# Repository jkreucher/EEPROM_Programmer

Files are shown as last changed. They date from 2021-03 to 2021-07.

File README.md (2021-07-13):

# Simple EEPROM Programmer

Copyright 2021 Jannik Kreucher

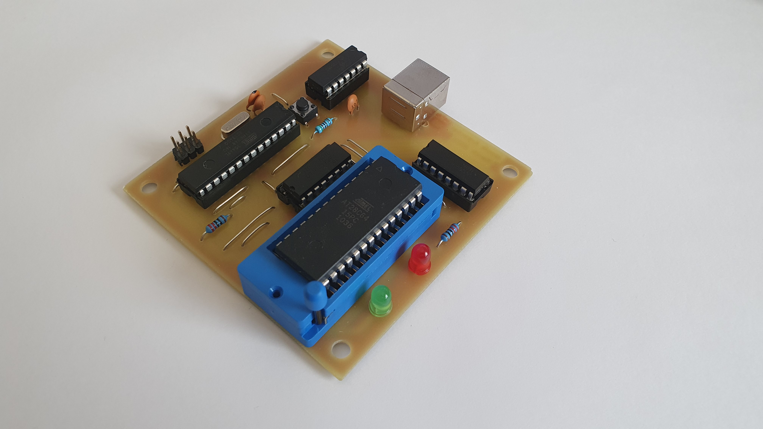
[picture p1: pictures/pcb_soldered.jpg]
PCB


## Table of Contents
 - [Project](#project)
 - [Dependencies](#dependencies)
 - [Make](#make)
 - [Flash EEPROM](#flash-eeprom)
 - [Schematic](#schematic)
   - [Processor](#micro-processor)
   - [Shift Registers](#shift-registers)
   - [EEPROM](#eeprom)
 - [PCB](#pcb)
 - [Enclosure](#enclosure)
 - [License](#license)

## Project

I created this programmer for my personal Z80 project. Since commerical programmers are fairly expensive I created my own simple programmer. It is nothing fancy and just supports a single family of [EEPROMs](https://en.wikipedia.org/wiki/EEPROM). It does not have support for a higher programming voltage and is limited for +5V EEPROMs.

This simple programmer supports following EEPROMs:
 - [28c64 (8k)](http://ww1.microchip.com/downloads/en/devicedoc/doc0001h.pdf)
 - [28c256 (32k)](http://ww1.microchip.com/downloads/en/DeviceDoc/doc0006.pdf)

## Dependencies

To compile the code you need to have following tools installed:
 - avr-gcc (with avr-libs)
 - avrdude
 - uisp

The programmer flash tool uses [Python3](https://www.python.org/) and [pySerial](https://pyserial.readthedocs.io/en/latest/pyserial.html):
 - python3
 - python3-serial

The Makefile contains a command to install everything needed:
```
cd code
sudo make tools
```

## Make

First compile the ATmega code. Execute following in the project root folder:
```
cd code
make
```

Now flash the compiled code to the programmer. *Connect the ISP-Programmer* and execute:
```
make fuses
make upload
```
I am using a USBasp Programmer. **Note: Notch on ISP-Programmer must be facing the ATmega8 chip (U1) while flashing firmware.**

## Flash EEPROM

**Note: Firmware needs to be flashed beforehand !**

To flash your binary file to the EEPROM inserted type:
```
cd code
chmod +x eeprom.py
./eeprom.py -e -o -p /dev/ttyACM0 -b 115200 -w <binaryfile.bin>
```

For more information:
```
./eeprom.py -h
```

## Schematic

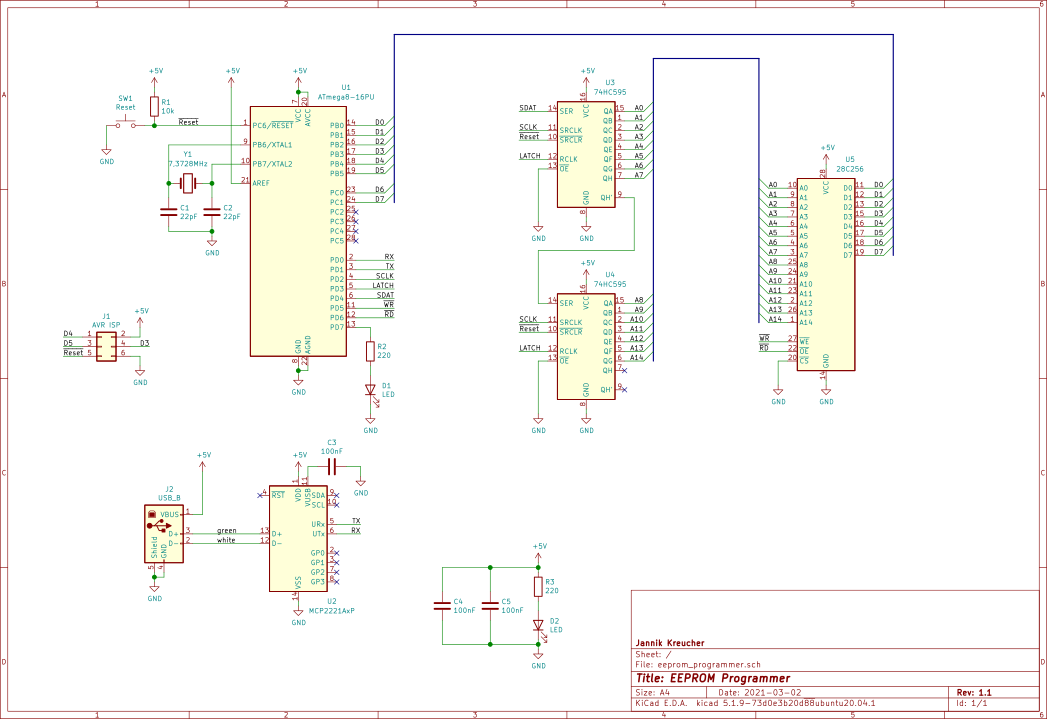
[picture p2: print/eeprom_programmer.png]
Schematic


### Micro Processor
The micro processor used in this project is the popular [ATmega8 (U1)](https://ww1.microchip.com/downloads/en/DeviceDoc/Atmel-2486-8-bit-AVR-microcontroller-ATmega8_L_datasheet.pdf), a cheaper version of the ATmega328 used in the [Arduino Uno](https://store.arduino.cc/arduino-uno-rev3). It handles everything: the serial communication, address bus and the data bus. U2 (MCP2221) handles the USB to UART conversion so no external ftdi cable is needed. The supply voltage is conveniantly given by the USB port also. Because data bus of the EEPROM is bidirectional it is directly connected to the processor. The micro processor needs to handle setting the bus as input or output. See [`eeprom.c`](code/eeprom.c) for everything I/O related. The UART is handled in [`uart.c`](code/uart.c). And the communication protocol is defined in [`parser.c`](code/parser.c) and in [`main.c`](code/main.c).

### Shift Registers
The shift registers (U3, U4) are utilized to expand the IO of the processor. Just 3 bits are needed to set the address bus to the target address. Since the address bus is only one way no data needs to be read from the address bus thus making shift registers the obvious choice for this situation. See [`eeprom.c: addrbus_set()`](code/eeprom.c) for how the data is latched.

### EEPROM

The EEPROM uses a parallel interface for communication. The address bus (A0-A14) is a parallel input which sets the memory location to read or write. The control lines ~WE and ~OE (active low) tell the EEPROM to read or write from/to the memory. The data is read from or sent out the parallel data bus (D0-D7) depending on the state of the control lines. Some EEPROMs have Write-Protect enabled. A algorithm (see datasheet) is implemented to deactivate write protection. See [`eeprom.c: eeprom_disable_protect()`](code/eeprom.c) for how this works.

## PCB

Note: The pcb is designed so that the top layer represents jumpers. The vias are large enough to stick a wire through.

For the schematic and pcb layout I used [KiCad](https://kicad.org/), a very awsome open source EDA. The clearances and spaces are designed for diy home etching so nothing really fancy. See [`eeprom_programmer_bom.pdf`](bom/eeprom_programmer_bom.pdf) for the bill of materials. At the moment the whole project would cost you around 26€ plus a weekend of time.

PCB

## Enclosure

The very simple, easy and fast to print enclosure consists of two parts which sandwhich the pcb. Needed are just *4x M3,5x12mm* wood screws to assemble the enclosure.

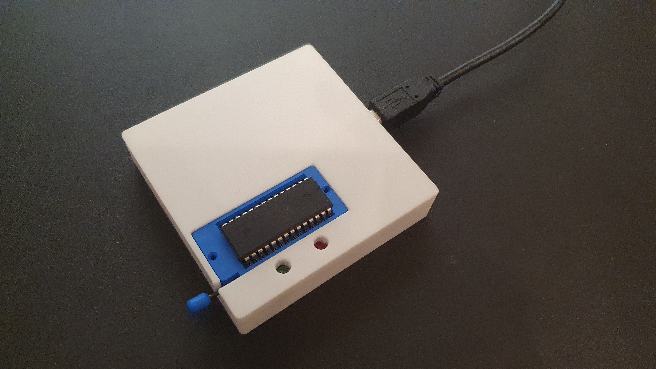
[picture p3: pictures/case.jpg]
Enclosure


## License

[MIT](LICENSE) Jannik Kreucher

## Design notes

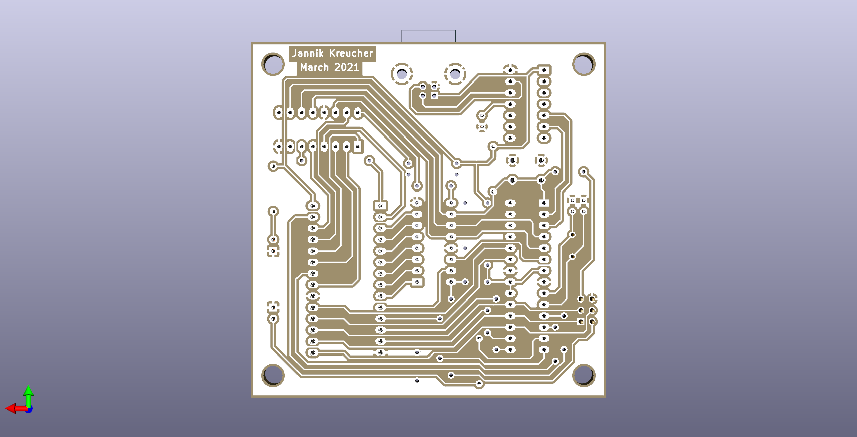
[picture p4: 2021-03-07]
pictures/eeprom_programmer_pcb_back.png

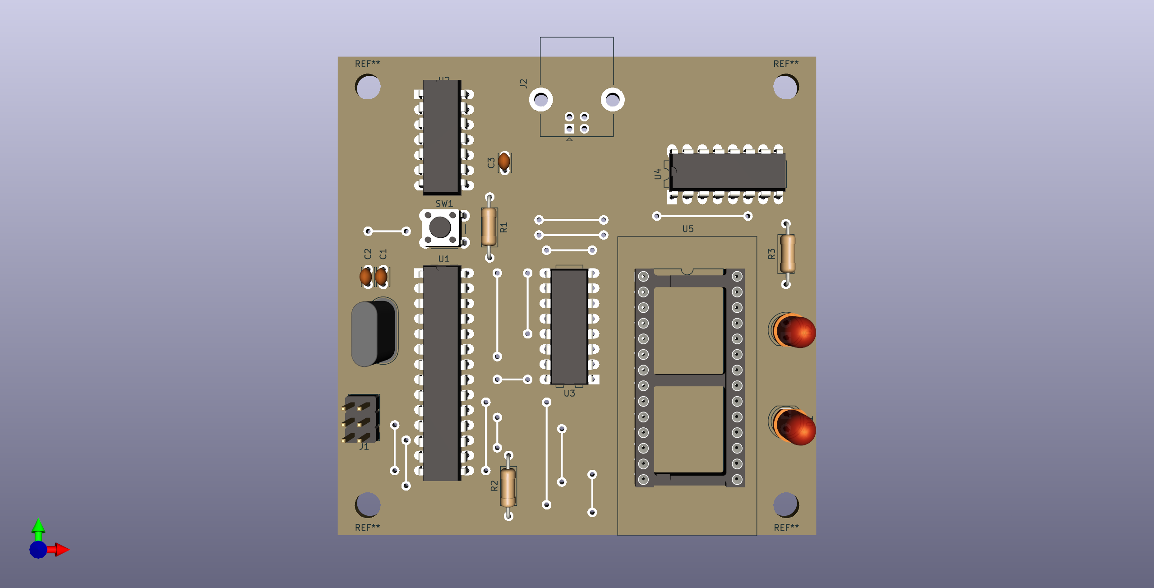
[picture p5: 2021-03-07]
pictures/eeprom_programmer_pcb_front.png

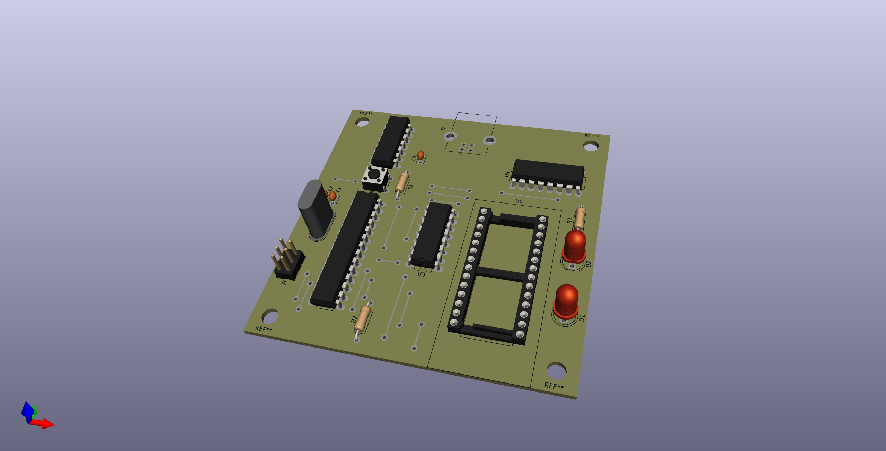
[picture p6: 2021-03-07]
pictures/eeprom_programmer_pcb_3d.png

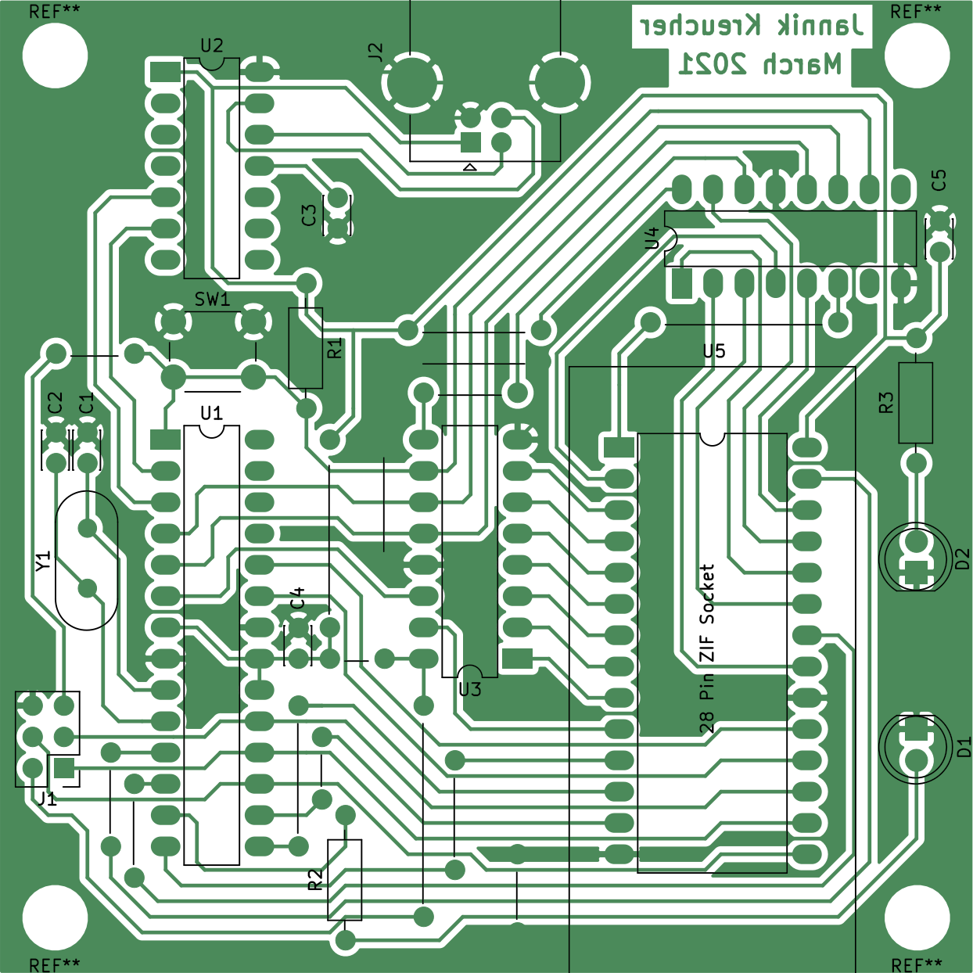
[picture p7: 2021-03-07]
gerber/eeprom_programmer-overlay.png

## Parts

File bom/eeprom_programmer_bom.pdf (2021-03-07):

# EEPROM Programmer BOM

07.03.2021 | Page 1
Designator | Value | Count | Shop | Order Num | Price | Sum
C1, C2 | 22pF | 2 | Reichelt.de | KERKO 22P | 0,051 € | 0,10 €
C3, C4, C5 | 100nF | 3 | Reichelt.de | KERKO 100N | 0,072 € | 0,22 €
D1, D2 | LED 5mm | 2 | Reichelt.de | LED 5MM GN | 0,070 € | 0,14 €
J1 | 02x03 Header | 1 | Reichelt.de | MPE 087-2-006 | 0,140 € | 0,14 €
J2 | USB Type B | 1 | Reichelt.de | USB BW | 0,300 € | 0,30 €
R1 | 10k | 1 | Reichelt.de | METALL 10,0K | 0,082 € | 0,08 €
R2, R3 | 220 | 2 | Reichelt.de | METALL 220 | 0,082 € | 0,16 €
SW1 | 6mm Switch | 1 | Reichelt.de | TASTER 9302 | 0,160 € | 0,16 €
U1 | ATmega8 | 1 | Reichelt.de ATMEGA 8-16 DIP | 1,620 € | 1,62 €
U2 | MCP2221 | 1 | Reichelt.de | MCP 2221-I/P | 2,350 € | 2,35 €
U3, U4 | 74HC595 | 2 | Reichelt.de | 74HC 595 | 0,310 € | 0,62 €
U5 | 28Pin ZIF | 1 | Reichelt.de | TEX 28 | 11,300 € | 11,30 €
Y1 | 7,3728MHz | 1 | Reichelt.de | 7,3728-HC49U-S | 0,220 € | 0,22 €
PCB | FR4 120x80 | 1 | Reichelt.de | EPCU 120X80 | 1,500 € | 1,50 €
Jumper | 0,6mm Wire | 1 | Reichelt.de | ZINN 0,6-40M | 6,550 € | 6,55 €
| | | | | Sum: | 25,46 €

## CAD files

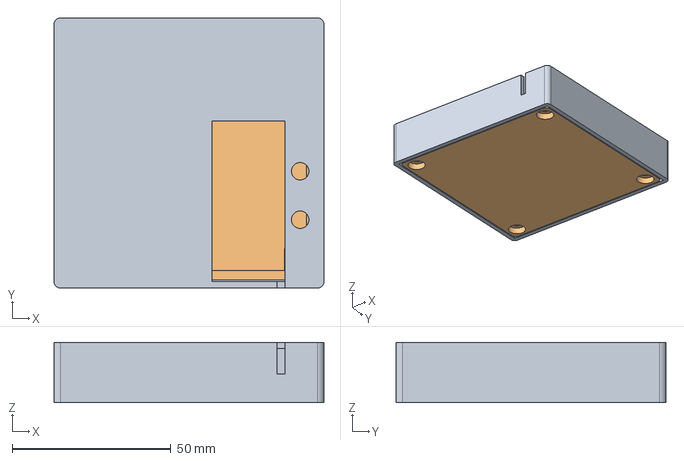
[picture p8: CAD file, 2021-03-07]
enclosure/eeprom_programmer_enclosure.FCStd
85.0 x 85.0 x 19.0 mm
Top_Part
Bottom_Part

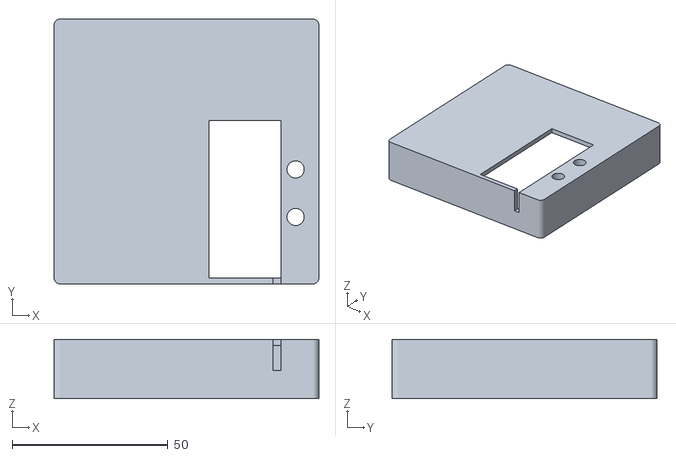
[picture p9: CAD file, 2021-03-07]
enclosure/eeprom_programmer_enclosure-Top_Part.stl
85.0 x 85.0 x 19.0

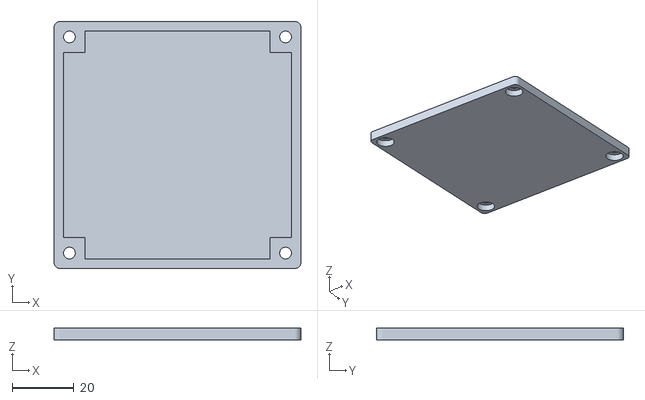
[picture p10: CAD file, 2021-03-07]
enclosure/eeprom_programmer_enclosure-Bottom_Part.stl
80.0 x 80.0 x 4.00

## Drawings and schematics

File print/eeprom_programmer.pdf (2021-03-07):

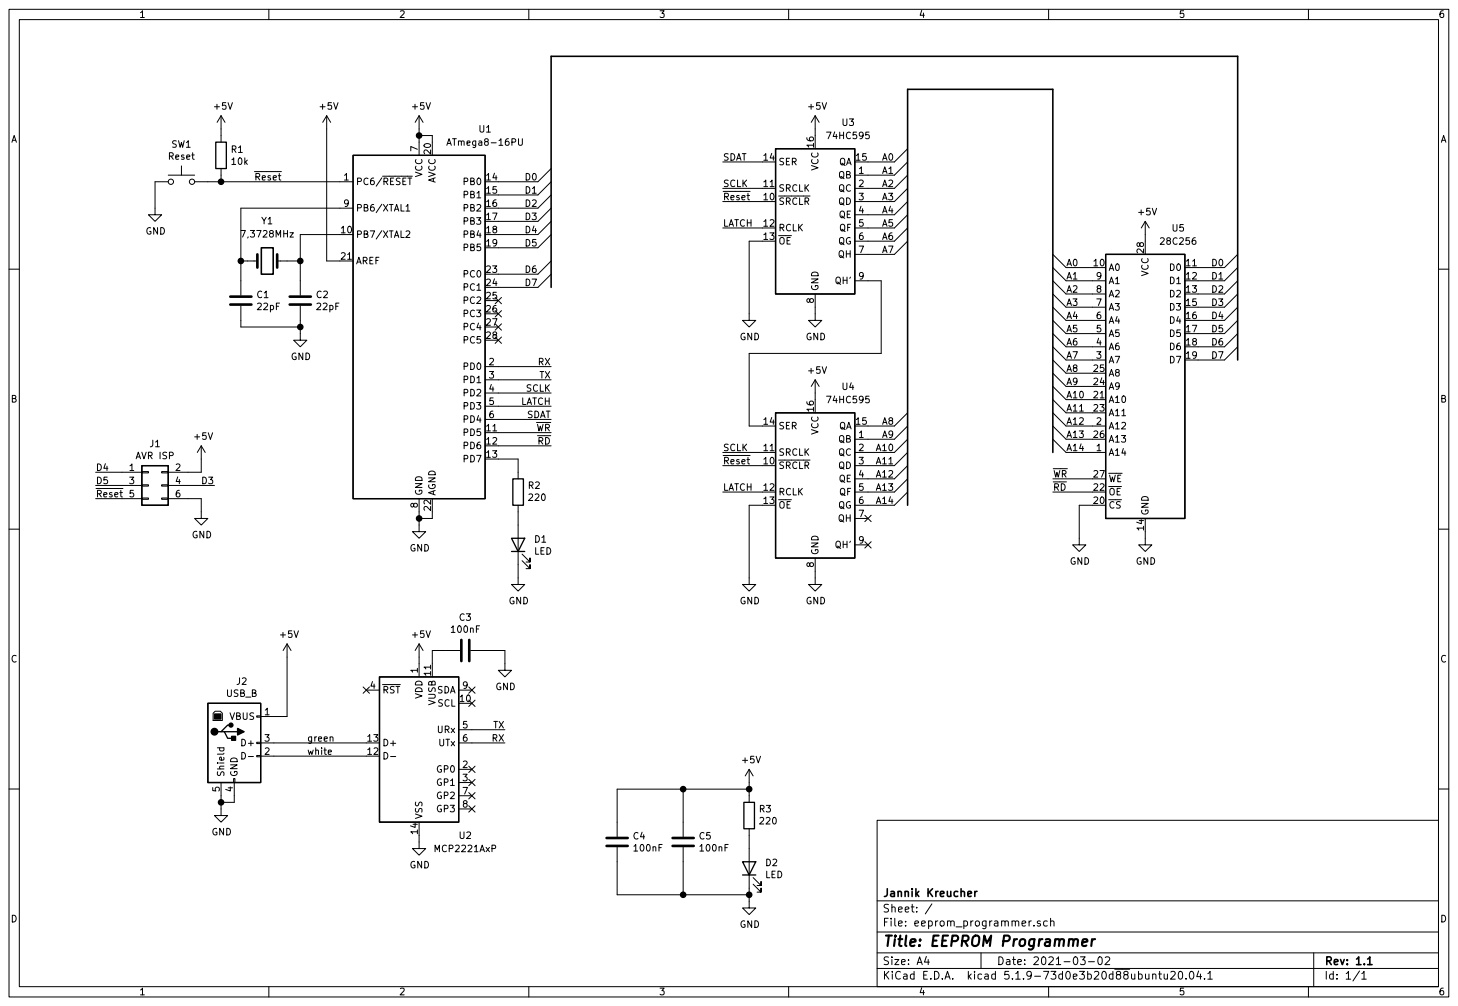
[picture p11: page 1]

74HC595 +5V GND GND GND GND

Id: 1/1 Title: EEPROM Programmer

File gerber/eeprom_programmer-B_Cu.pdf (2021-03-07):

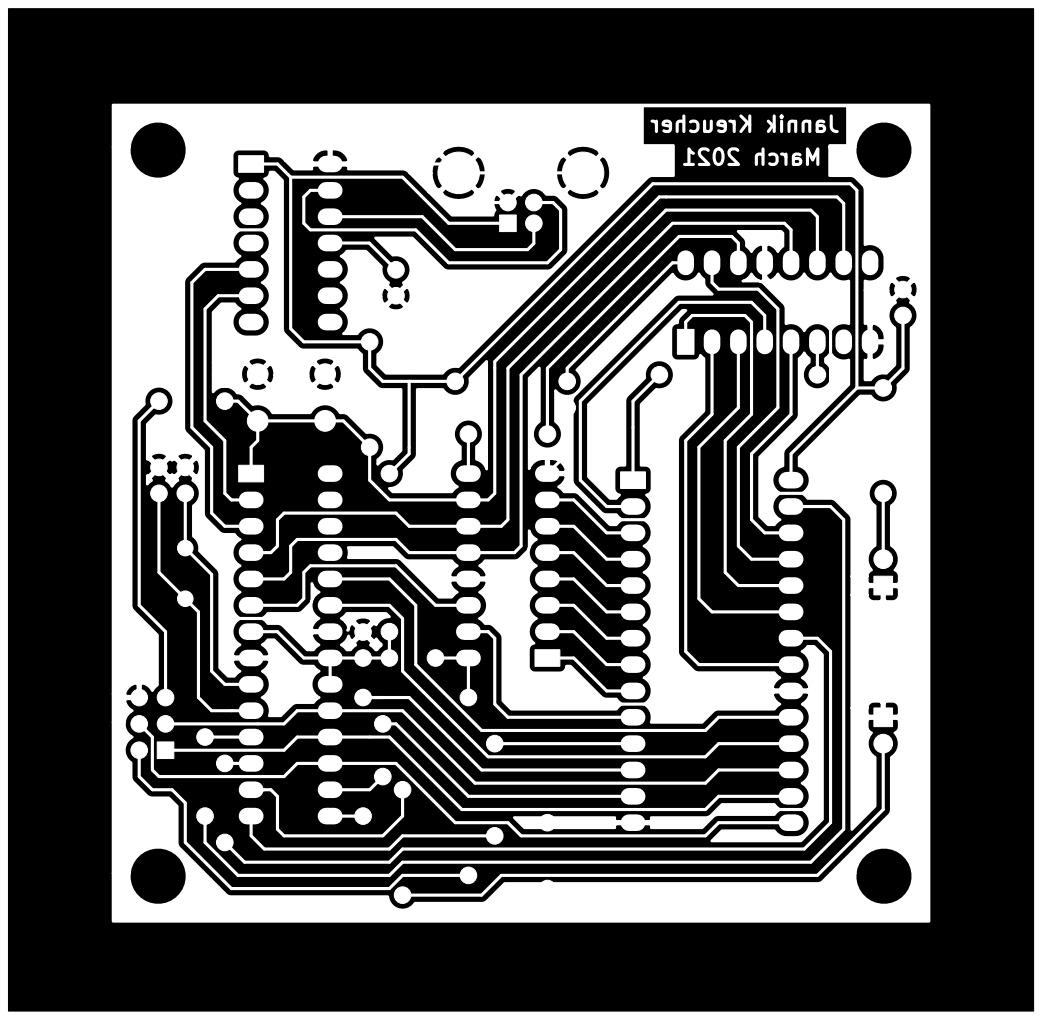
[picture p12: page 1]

File: eeprom_programmer.kicad_pcb Sheet: Jannik Kreucher Note: front Layer are wire jumpers

Id: 1/1 Title: EEPROM Programmer

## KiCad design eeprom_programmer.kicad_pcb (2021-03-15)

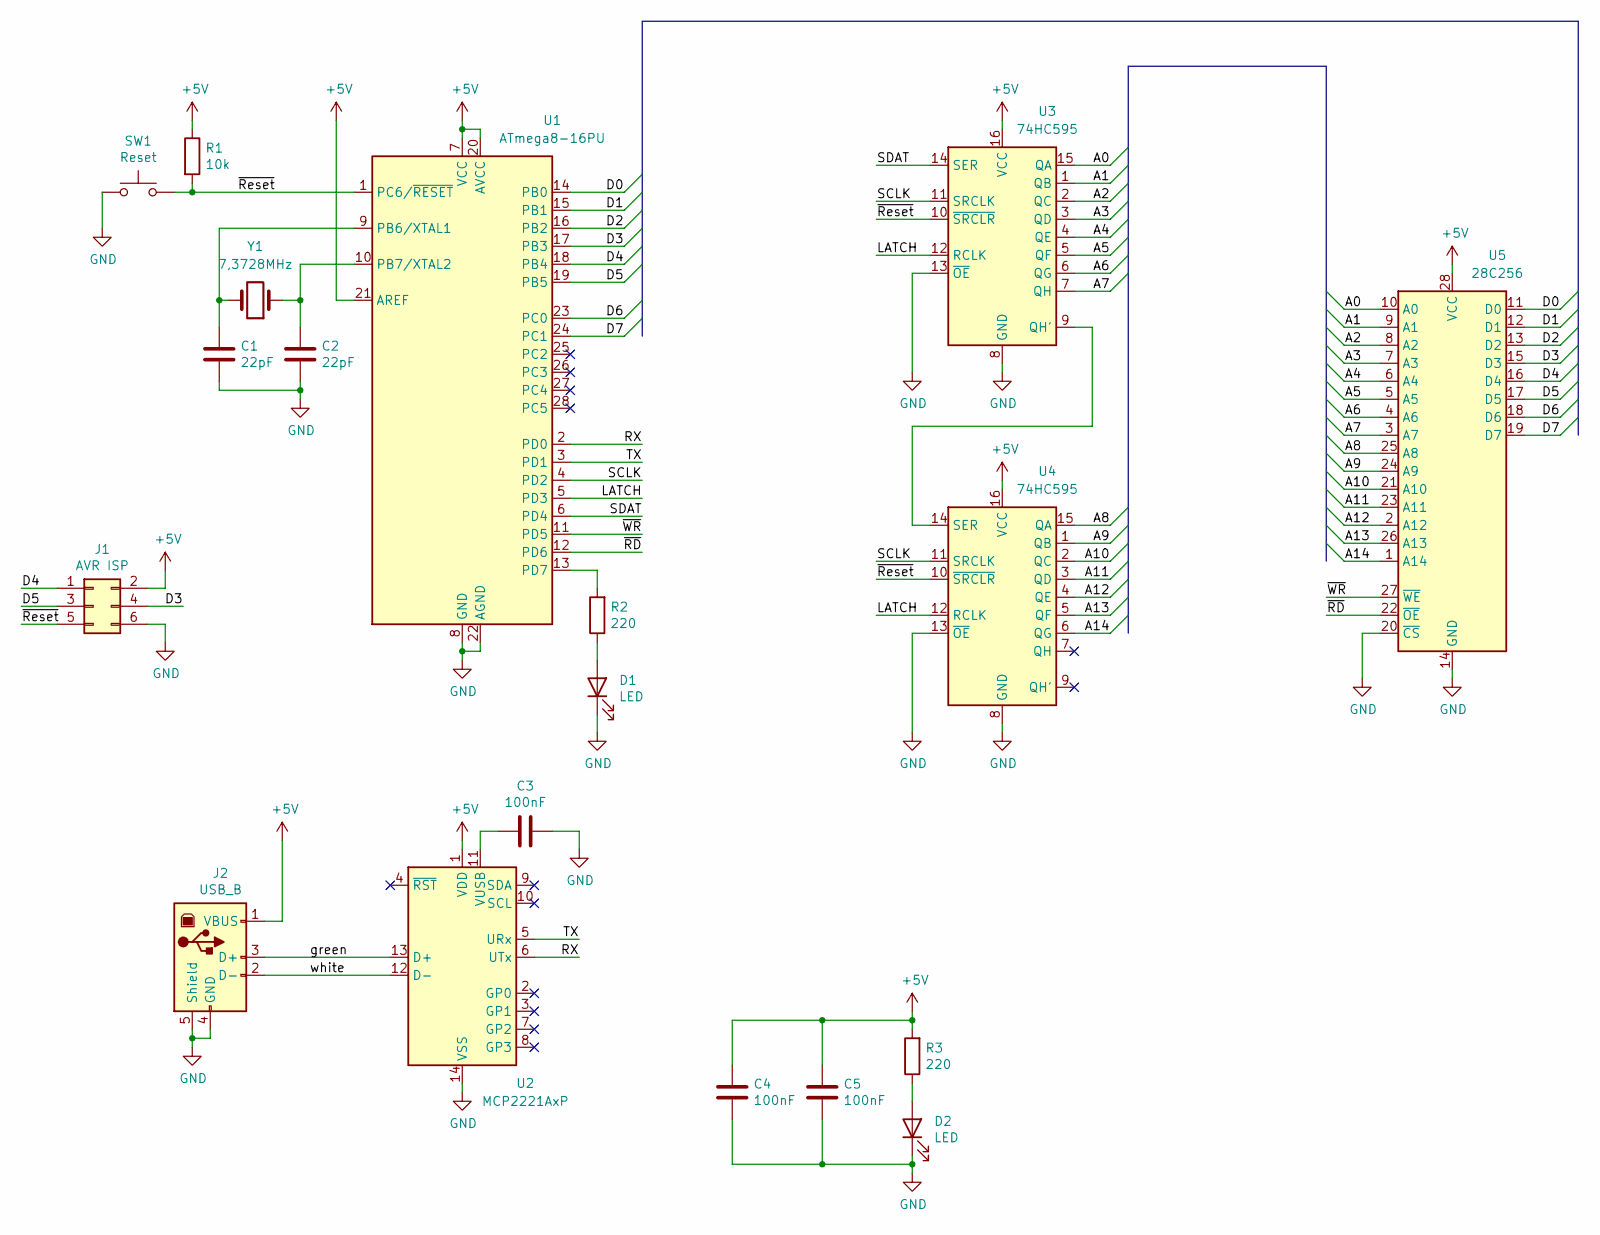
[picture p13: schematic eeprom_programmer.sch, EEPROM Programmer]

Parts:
C1, C2: 22pF; C_Disc_D3.0mm_W2.0mm_P2.50mm
C3, C4, C5: 100nF; C_Disc_D3.0mm_W2.0mm_P2.50mm
D1, D2: LED; LED_D5.0mm
J1: AVR ISP; PinHeader_2x03_P2.54mm_Vertical
J2: USB_B; USB_B_Lumberg_2411_02_Horizontal
R1: 10k; R_Axial_DIN0207_L6.3mm_D2.5mm_P10.16mm_Horizontal
R2, R3: 220; R_Axial_DIN0207_L6.3mm_D2.5mm_P10.16mm_Horizontal
SW1: Reset; SW_PUSH_6mm
U1: ATmega8-16PU; DIP-28_W7.62mm_LongPads
U2: MCP2221AxP; DIP-14_W7.62mm_LongPads
U3, U4: 74HC595; DIP-16_W7.62mm_LongPads
U5: 28C256; DIP-28_W15.24mm_ZIF_LongPads
Y1: 7,3728MHz; Crystal_HC49-U_Vertical

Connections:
+5V: C4.1, C5.1, J1.2, J2.1 (VBUS), R1.1, R3.2, U1.7 (VCC), U1.20 (AVCC), U1.21 (AREF), U2.1 (VDD), U3.16 (VCC), U4.16 (VCC), U5.28 (VCC)
/A0: U3.15 (QA), U5.10 (A0)
/A1: U3.1 (QB), U5.9 (A1)
/A2: U3.2 (QC), U5.8 (A2)
/A3: U3.3 (QD), U5.7 (A3)
/A4: U3.4 (QE), U5.6 (A4)
/A5: U3.5 (QF), U5.5 (A5)
/A6: U3.6 (QG), U5.4 (A6)
/A7: U3.7 (QH), U5.3 (A7)
/A8: U4.15 (QA), U5.25 (A8)
/A9: U4.1 (QB), U5.24 (A9)
/A10: U4.2 (QC), U5.21 (A10)
/A11: U4.3 (QD), U5.23 (A11)
/A12: U4.4 (QE), U5.2 (A12)
/A13: U4.5 (QF), U5.26 (A13)
/A14: U4.6 (QG), U5.1 (A14)
/D0: U1.14 (PB0), U5.11 (D0)
/D1: U1.15 (PB1), U5.12 (D1)
/D2: U1.16 (PB2), U5.13 (D2)
/D3: J1.4, U1.17 (PB3), U5.15 (D3)
/D4: J1.1, U1.18 (PB4), U5.16 (D4)
/D5: J1.3, U1.19 (PB5), U5.17 (D5)
/D6: U1.23 (PC0), U5.18 (D6)
/D7: U1.24 (PC1), U5.19 (D7)
/LATCH: U1.5 (PD3), U3.12 (RCLK), U4.12 (RCLK)
/RX: U1.2 (PD0), U2.6 (UTx)
/SCLK: U1.4 (PD2), U3.11 (SRCLK), U4.11 (SRCLK)
/SDAT: U1.6 (PD4), U3.14 (SER)
/TX: U1.3 (PD1), U2.5 (URx)
/green: J2.3 (D+), U2.13 (D+)
/white: J2.2 (D-), U2.12 (D-)
/~RD: U1.12 (PD6), U5.22 (~OE)
/~Reset: J1.5, R1.2, SW1.2, U1.1 (PC6/~RESET), U3.10 (~SRCLR), U4.10 (~SRCLR)
/~WR: U1.11 (PD5), U5.27 (~WE)
GND: C1.2, C2.2, C3.1, C4.2, C5.2, D1.1 (K), D2.1 (K), J1.6, J2.4 (GND), J2.5 (Shield), SW1.1, U1.8 (GND), U1.22 (AGND), U2.14 (VSS), U3.8 (GND), U3.13 (~OE), U4.8 (GND), U4.13 (~OE), U5.14 (GND), U5.20 (~CS)
unnamed: C1.1, U1.9 (PB6/XTAL1), Y1.2
unnamed: C2.1, U1.10 (PB7/XTAL2), Y1.1
unnamed: C3.2, U2.11 (VUSB)
unnamed: D1.2 (A), R2.1
unnamed: D2.2 (A), R3.1
unnamed: R2.2, U1.13 (PD7)
unnamed: U3.9 (QH'), U4.14 (SER)

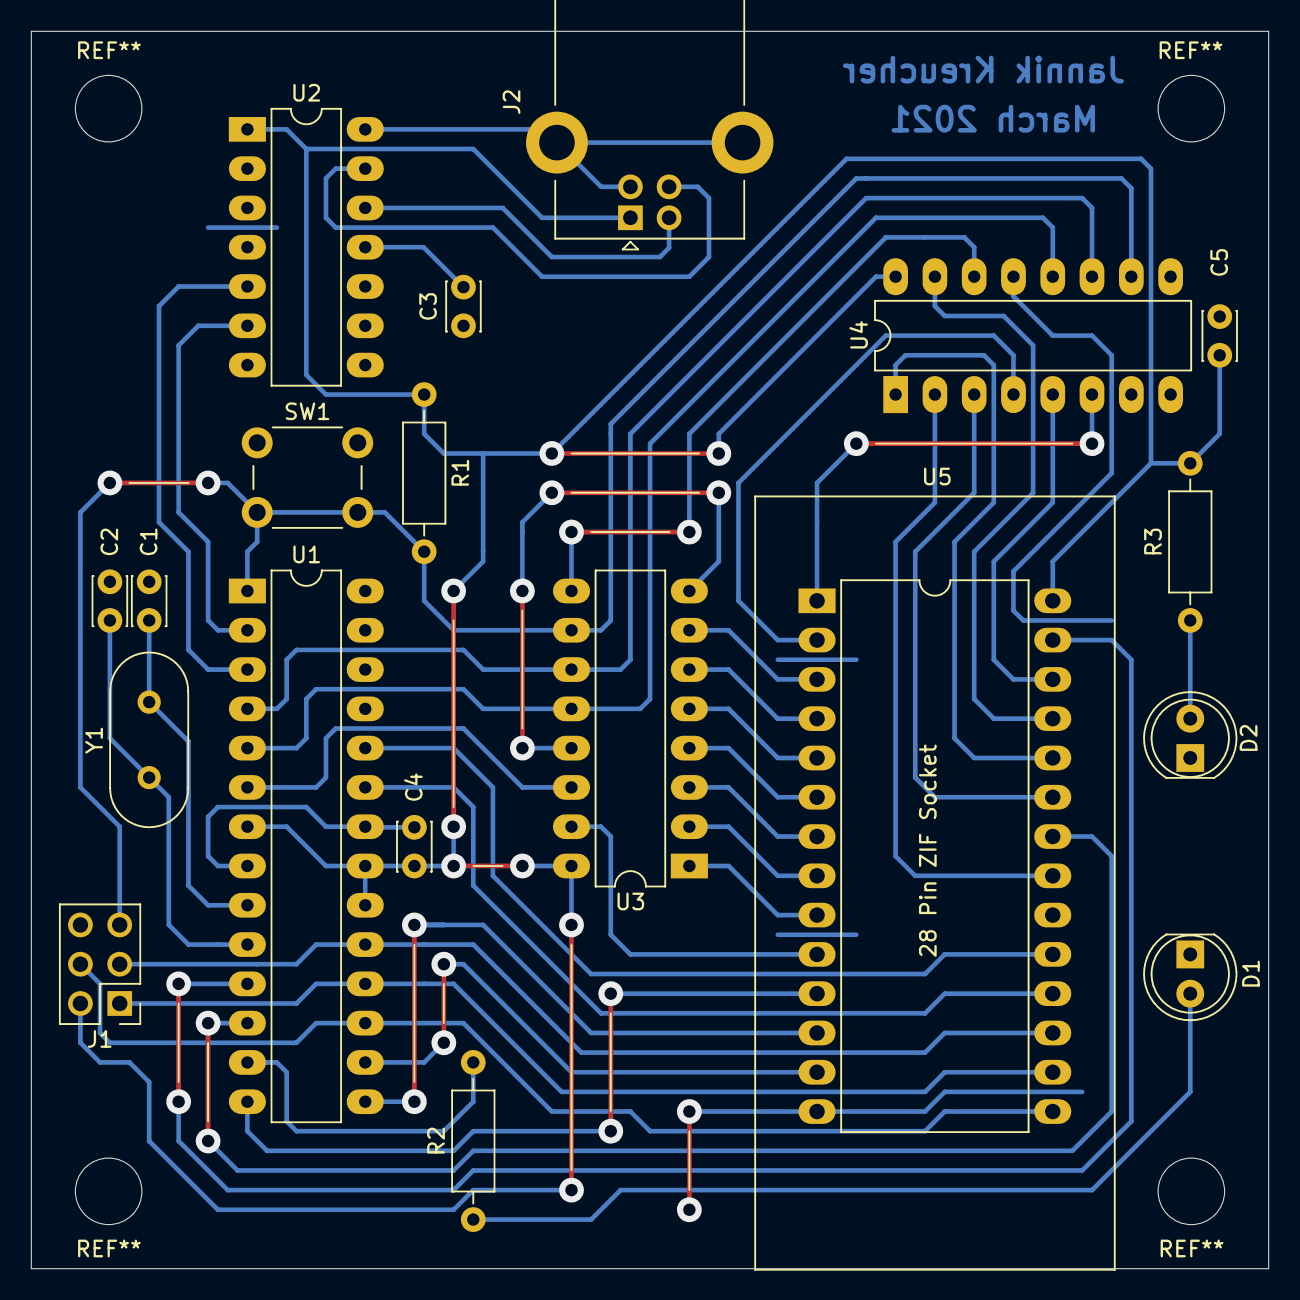
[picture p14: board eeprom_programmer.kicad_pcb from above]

Board: 2 copper layers, 80.0 x 80.0 mm, 19 parts (0 on the bottom side), 42 nets.

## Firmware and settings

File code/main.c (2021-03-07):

#include "uart.h"
#include "eeprom.h"
#include "parser.h"


char help_text[] =
"EEPROM PROGRAMMER v1.1\r\n"
"**********************\r\n"
"by Jannik Kreucher\r\n\n"
"h         - Help\r\n"
"d         - Disable write protect\r\n"
"w AAAA DD - Write to EEPROM\r\n"
"r AAAA    - Read from EEPROM\r\n"
"return: Byte in EEPROM\r\n"
"Everything in hex format!\r\n\n";


int main() {
	// some setup stuff
	eeprom_init();
	uart_init();

	uart_tx_string(help_text);	

	// uart rx char, data for eeprom
	unsigned char c, data;
	unsigned short address;

	while(1) {
		// first command character
		c = uart_wait_rx();

		// help text
		if(c == 'h') {
			PORTD |= PIN_LED;
			uart_tx_string(help_text);
			PORTD &= ~PIN_LED;
		}
		// disable write protect
		else if(c == 'd') {
			eeprom_disable_protect();
			uart_tx_byte('d');
		}
		// write to eeprom
		else if(c == 'w') {
			address = parse_byte();                  // higher byte first
			address = (address << 8) | parse_byte(); // then lower byte
			data    = parse_byte();                  // now data
			// write to eeprom
			data = eeprom_write_validate(address, data);
			// send written data back via uart
			uart_tx_byte( bin_to_hex( data >> 4 ) );
			uart_tx_byte( bin_to_hex( data ) );
		}
		// read from eeprom
		else if(c == 'r') {
			address = parse_byte();                  // higher byte first
			address = (address << 8) | parse_byte(); // then lower byte
			// read from eeprom
			data = eeprom_read(address);
			// send back via uart
			uart_tx_byte( bin_to_hex( data >> 4 ) );
			uart_tx_byte( bin_to_hex( data ) );
		}

	}

	return 0;
}

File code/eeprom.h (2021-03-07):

#ifndef EEPROM_H_
#define EEPROM_H_

#include <avr/io.h>
#include <util/delay.h>

#define PIN_SCLK	(1<<2) // PD2: Shift Register Serial Clock
#define PIN_LATCH	(1<<3) // PD3: Shift Register RClock
#define PIN_SDAT	(1<<4) // PD4: Shift Register Serial Data
#define PIN_WR		(1<<5) // PD5: EEPROM Write Enable (active low)
#define PIN_RD		(1<<6) // PD6: EEPROM Read Enable (active low)
#define PIN_LED		(1<<7) // PD7: Status LED


void eeprom_init();

void databus_input();
void databus_output();

void databus_set(unsigned char data);
unsigned char databus_get();

void addrbus_set(unsigned short addr);

void eeprom_write(unsigned short addr, unsigned char data);
unsigned char eeprom_write_validate(unsigned short addr, unsigned char data);
unsigned char eeprom_read(unsigned short addr);

void eeprom_disable_protect();

#endif

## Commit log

2021-03-07 readme enclosure picture
    [eeprom_programmer.kicad_pcb, eeprom_programmer.sch, eeprom_programmer_bom.ods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]
2021-03-07 readme schematic
2021-03-07 readme overlay picture
    [eeprom_programmer.kicad_pcb]
2021-03-15 eeprom.py serial flush fix
    [eeprom_programmer.kicad_pcb]
2021-03-16 eeprom.py progress bar rounding fix
    [eeprom.py]
2021-03-18 parser reverse order fix
    [eeprom.c]
